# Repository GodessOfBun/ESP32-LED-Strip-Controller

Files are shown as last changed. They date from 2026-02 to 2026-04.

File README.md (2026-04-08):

## Introduction:front_3D

This ESP32-C2 Based board is designed to control up to 5 channels of an LED Strip. Each channel is in theory capable of 4A up to 24V with the total current drawn from the board not exceeding 5A. Although in theory there isn't much preventing it from reaching 8A current(eFuse max) other than trace width and the bulk capacitor and so on.
Mosfet remains below 50c with a 99% duty cycle at 2.4A/24v @ 25KHz in testing. In theory, according to my calculations, it can easily handle 4A or even 4.5A/5A. above 4A is not recommended. It is compatible with Matter (using the code I'm too eepy and busy to upload right now) and HA with ESPHome. If you use HA  you might as well save yourself the trouble and use ESPHome as Matter can have it's own shortcomings.

Measured Channel FET rise time: 12.5ns.

eFuse can be skipped by shorting the VIN to EFUSE to the output with a wire.

The board is designed for 25KHz in mind but can be used with a lower or higher frequency within reason.

You can leave unused channnels empty and not solder them to save on cost. 

The EFUSE is connfigured to be triggered at 5.51A. It features a 150ms-300ms~ soft-start to prevent sparks when connecting the power.

Note: It features a 0201 test LED originally used as a fun challenge for soldering. I suggest changing it to a 0602/0402 package if using it in practice or debugging with it as it can be very challenging to solder.

A IPEX connector is used to debug and monitor the 3.3v rail ripple and transient performance. Note however that the 50 ohm termination seems to not be working, I will confirm why when the project is finished as it's not essential and works perfectly fine with a probe tip to BNC adapter as the probe is designed to be purposely lossy and cancel ringing. A BNC to IPEX Cable is recommended. Note that IPEX connectors are not meant for frequent unplugging and replugging. The socket is rated for 30-50 mating cycles

### Notes:
Frequency of 2.2MHz was chosen for the 3.3v rail to improve transient response and performance/size of the buck converter. Efficiency is not a big concern for such an application.
An eFuse (Hot-swap controller) was chosen for this board to prevent sparking upon plugging in and to reduce the required footprint for an ressetable poly fuse that can withstand 40-30v at 5A.

## Potential  Improvemtns:
- [ ] Add a factory reset button seperate from BOOT
- [ ] External antenna instead of built-in PCB
- [ ] Switch from ESP32-C2 to C3 or similiar for better matter compatbility and performance.
- [ ] Use a dedicated ESP32 IC instead of a pre-made module as the PCB is already 4 layers hence the impedance matching is very easy and does not add additional cost.
- [ ] Add a polymer/tantalum bulk cap for esp32 to reduce wifi transmission transients. This will require some consideration to prevent ringing at the output.
- [ ] Calculate and confirm feed-forward capacitor for the 3.3v rail. (It is picked based on gut feeling)
- [ ] Improve hand-solderability, use bigger TVS diodes.
- [ ] Add jumper for 3.3v from programming header.
- [ ] (?) Debug LED for each channel
- [ ] (?) RGB Indicator LED for when WiFI is connected and device is commisioned.
- [ ] (?) Software based SSFM solution for each channel to reduce EMI emitted from the LED Strips as they are difficult to shield and user assembled. For a simpler but less effective solution, Each channel can operate at a slightly different ferquency.
- [ ] (?) eFuse skip jumper.

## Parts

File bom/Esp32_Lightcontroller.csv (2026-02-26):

Id | Designator | Footprint | Quantity | Designation | Supplier and ref
1 | C13,C20,C18 | C_0805_2012Metric | 3 | 1uF
2 | Q4,Q5,Q3,Q2,Q1 | SOT-23 | 5 | SI2318A
3 | L1 | L_Coilcraft_XAL6060-XXX | 1 | 8.2uH
4 | C14 | C_0402_1005Metric | 1 | 47pF
5 | R10 | R_0603_1608Metric | 1 | 22.1k 1%
6 | R4 | R_0603_1608Metric | 1 | 3kR 1%
7 | C21,C19,C5,C4 | C_1210_3225Metric | 4 | 10uF
8 | R3,R5,R7,R11,R9 | R_0603_1608Metric | 5 | 5
9 | C8,C10,C11,C9,C6,C27 | C_0402_1005Metric | 6 | 100nF
10 | C22 | C_0805_2012Metric | 1 | 4.7uF (X7R)
11 | U3,U4,U7,U5,U6 | SOT95P280X145-5N | 5 | UCC27517DBVR
12 | C2 | C_1206_3216Metric | 1 | 2.2uF
13 | D6 | LED_0603_1608Metric | 1 | LED_ON
14 | R13 | R_0603_1608Metric | 1 | 330R
15 | TP2 | TestPoint_Pad_D1.5mm | 1 | GPIO6
16 | U1 | ESP32-C2-C12 | 1 | ESP32-C2-C12
17 | R15 | R_0603_1608Metric | 1 | 50R Ter(opt)
18 | J3 | TerminalBlock_MaiXu_MX126-5.0-06P_1x06_P5.00mm | 1 | LED_Connector
19 | FB1 | Ferrite_0603_1608Metric | 1 | 600R 100mhz
20 | TP6 | U.FL_Molex_MCRF_73412-0110_Vertical | 1 | UMCC
21 | C16,C12,C3 | C_0603_1608Metric | 3 | 100nF
22 | SW1 | SW_Push_SPST_NO_Alps_SKRK | 1 | RST
23 | U8 | SOIC-8_3.9x4.9mm_P1.27mm | 1 | LM317L_SOT-89
24 | C7 | CP_Elec_6.3x7.7 | 1 | 100uF
25 | D13 | LED_0201_0603Metric | 1 | P18
26 | C15 | C_1206_3216Metric | 1 | 1uF
27 | U9 | TSOT-23-6 | 1 | AP64060WU-7
28 | C17 | CP_Radial_D10.0mm_P5.00mm | 1 | 470uF
29 | TP3 | TestPoint_Pad_D1.5mm | 1 | GPIO7
30 | R12 | R_0603_1608Metric | 1 | 69.8k 1%
31 | J1 | PinHeader_2x03_P1.27mm_Vertical | 1 | Conn_programmer
32 | C1 | C_1210_3225Metric | 1 | 10uF (50v)
33 | TP1 | TestPoint_Pad_D1.5mm | 1 | GPIO5
34 | R1,R2 | R_0603_1608Metric | 2 | 500
35 | 3.3v1 | Scope_probe_pad | 1 | Probe_3v3
36 | R6 | R_0603_1608Metric | 1 | 470R 1%
37 | J2 | TerminalBlock_CUI_TB007-508-02_1x02_P5.08mm_Horizontal | 1 | PWR
38 | SW2 | SW_Push_SPST_NO_Alps_SKRK | 1 | BOOT
39 | TP5 | TestPoint_Pad_D1.5mm | 1 | GPIO18
40 | TP4 | TestPoint_Pad_D1.5mm | 1 | GPIO10
41 | R14 | R_0201_0603Metric | 1 | 330R
42 | D2,D3,D4 | D_SOD-323 | 3 | 1N5819WS
43 | D11,D12,D8,D9,D10 | D_SOD-523 | 5 | 5v
44 | C24 | C_0402_1005Metric | 1 | 10nF
45 | C26 | C_0402_1005Metric | 1 | 8nF
46 | D5,D1 | D_SOD-323 | 2 | B5819WS
47 | D14 | D_SOD-123 | 1 | D_Schottky
48 | R18 | R_0603_1608Metric | 1 | 1M
49 | R17 | R_0603_1608Metric | 1 | 330k
50 | U2 | VQFN24_RGE_TEX | 1 | TPS259807ONRGER
51 | R8 | R_0603_1608Metric | 1 | 330
52 | C25 | C_0402_1005Metric | 1 | 68nF
53 | D7 | D_SOD-123F | 1 | TVS (26v)
54 | C23 | C_0402_1005Metric | 1 | 4.3nF
55 | R16 | R_0603_1608Metric | 1 | 2.21k

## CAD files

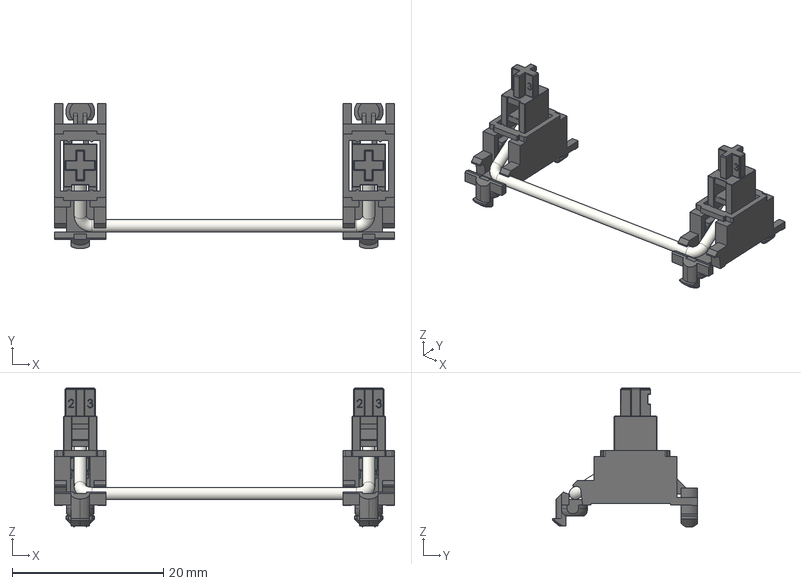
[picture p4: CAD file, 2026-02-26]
Footprints/kiswitch-main/source_3d/Mounting_Keyboard_Stabilizer/Stabilizer_Cherry_MX_3u.FCStd
44.9 x 19.2 x 18.3 mm
Bar
Stabilizer_Key_
Stabilizer_Base_
Stabilizer_Key
Stabilizer_Base

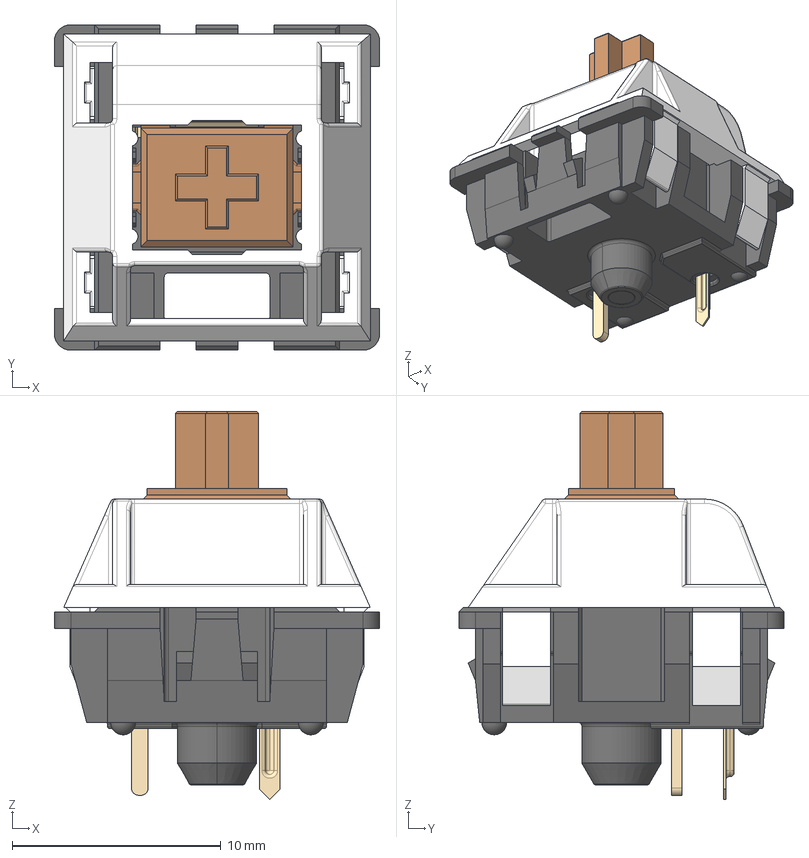
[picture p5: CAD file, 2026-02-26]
Footprints/kiswitch-main/source_3d/Switch_Keyboard_Cherry_MX/SW_Cherry_MX_Plate.FCStd
15.6 x 15.6 x 18.6 mm
Lower_Housing
Upper_Housing
Stem
Pin_1
Pin_2
Spring
Clicker

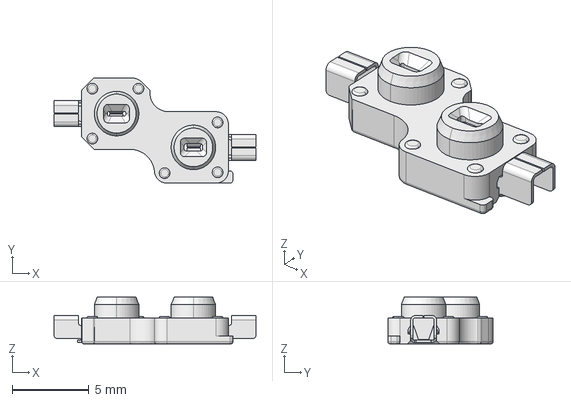
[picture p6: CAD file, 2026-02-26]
Footprints/kiswitch-main/source_3d/Switch_Keyboard_Kailh/SW_Hotswap_Kailh_Choc_v1.FCStd
13.2 x 6.85 x 3.05 mm

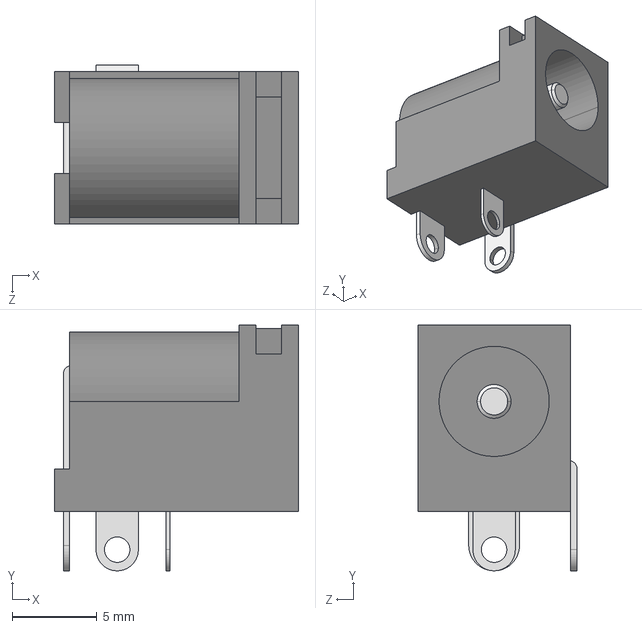
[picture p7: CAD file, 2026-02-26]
Footprints/PJ-002AH/PJ-002AH.step
14.4 x 14.5 x 9.40 mm

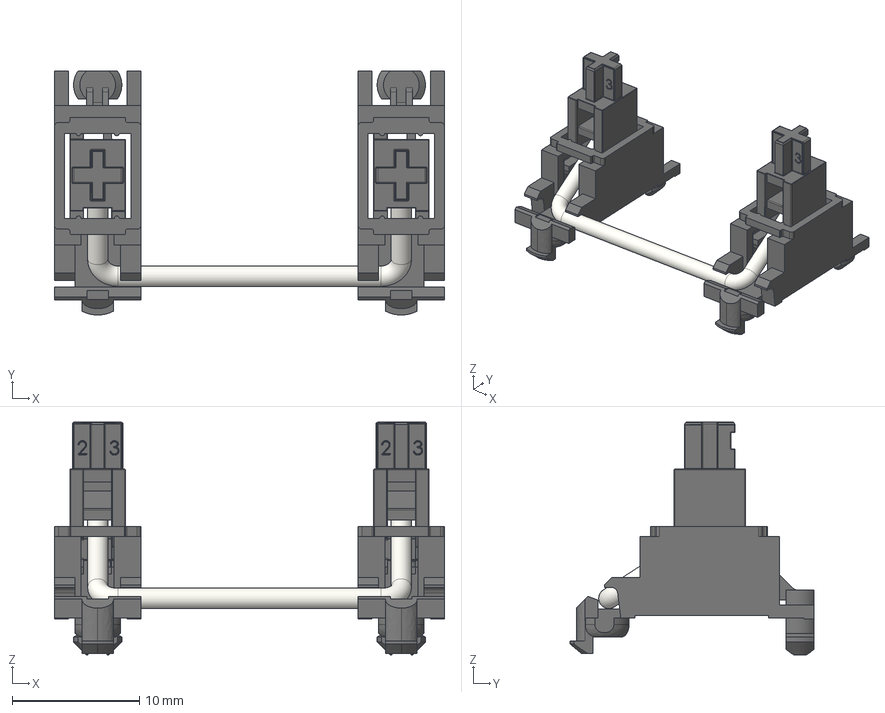
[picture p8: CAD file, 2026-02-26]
Footprints/kiswitch-main/source_3d/Mounting_Keyboard_Stabilizer/Stabilizer_Cherry_MX_2u.FCStd
30.7 x 19.2 x 18.3 mm
Bar
Stabilizer_Key_
Stabilizer_Base_
Stabilizer_Key
Stabilizer_Base

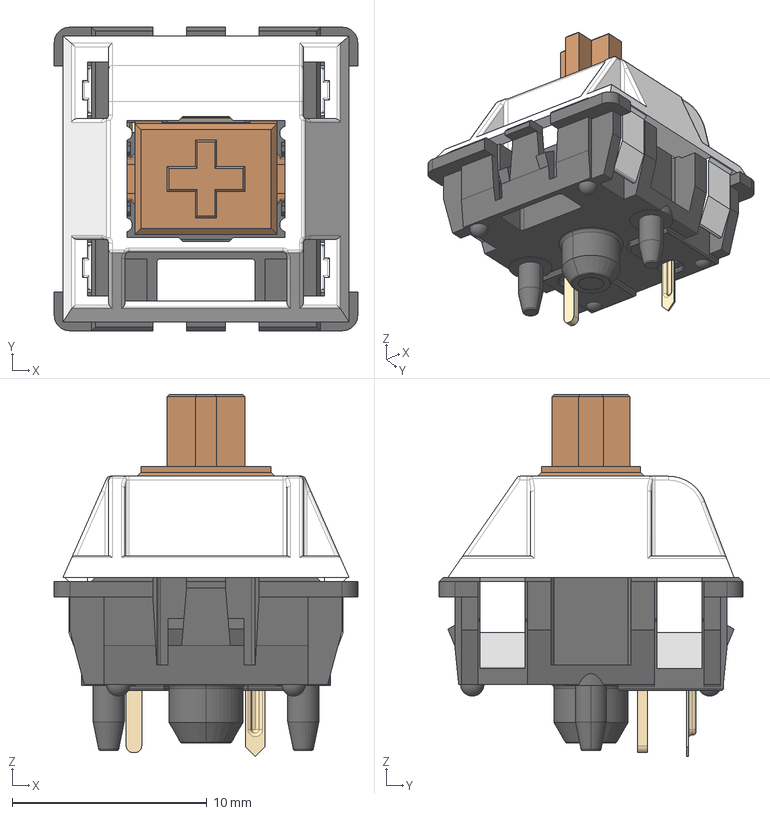
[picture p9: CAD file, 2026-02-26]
Footprints/kiswitch-main/source_3d/Switch_Keyboard_Cherry_MX/SW_Cherry_MX_PCB.FCStd
15.6 x 15.6 x 18.6 mm
Lower_Housing
Upper_Housing
Stem
Pin_1
Pin_2
Spring
Clicker

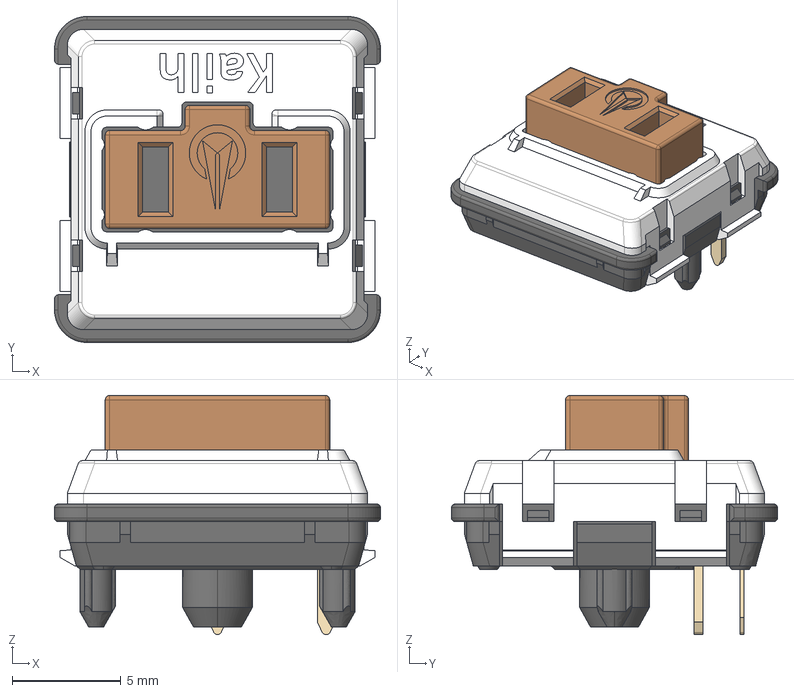
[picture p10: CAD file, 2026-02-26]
Footprints/kiswitch-main/source_3d/Switch_Keyboard_Kailh/SW_Kailh_Choc_V1.FCStd
15.0 x 15.0 x 11.0 mm
Upper_Housing
Lower_Housing
Stem
Pin_2
Pin_1

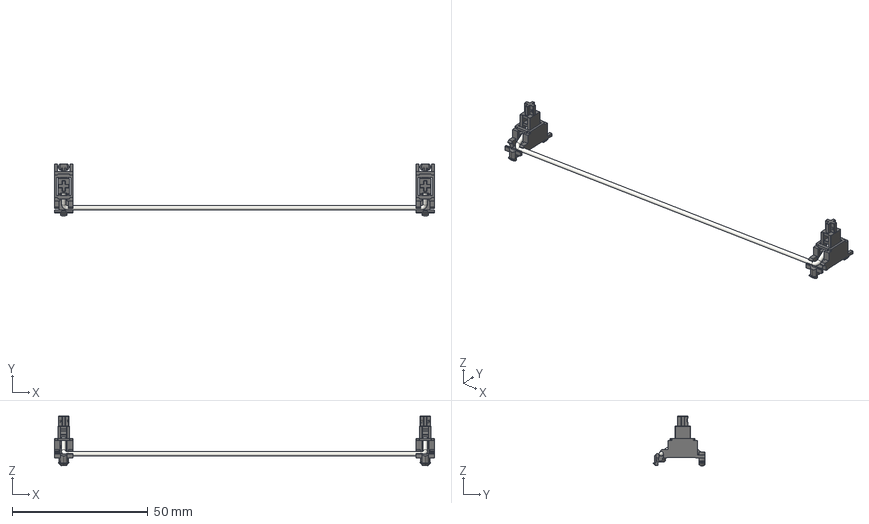
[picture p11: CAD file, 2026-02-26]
Footprints/kiswitch-main/source_3d/Mounting_Keyboard_Stabilizer/Stabilizer_Cherry_MX_8u.FCStd
140.1 x 19.2 x 18.3 mm
Bar
Stabilizer_Key_
Stabilizer_Base_
Stabilizer_Key
Stabilizer_Base

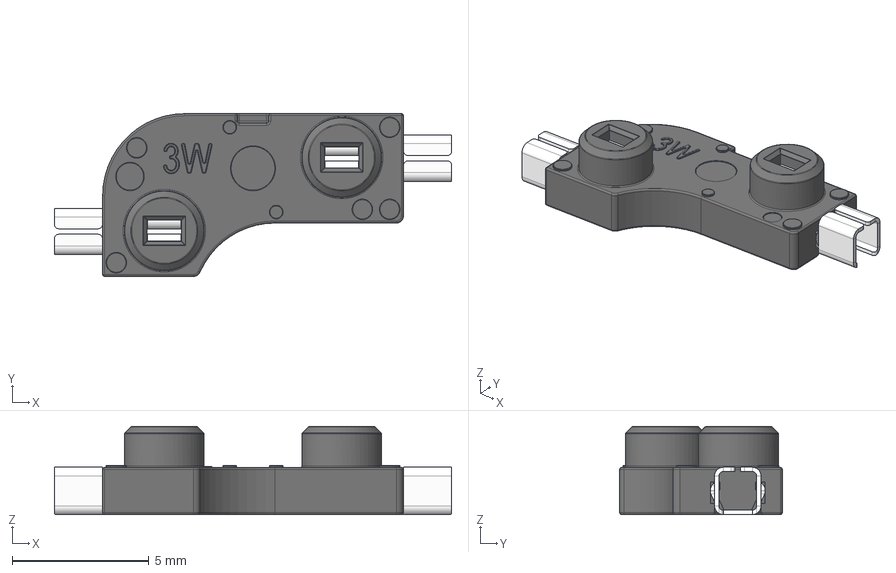
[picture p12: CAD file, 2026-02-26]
Footprints/kiswitch-main/source_3d/Switch_Keyboard_Kailh/SW_Hotswap_Kailh.FCStd
14.5 x 5.95 x 3.22 mm
Pin_1
Pin_2
Plastic

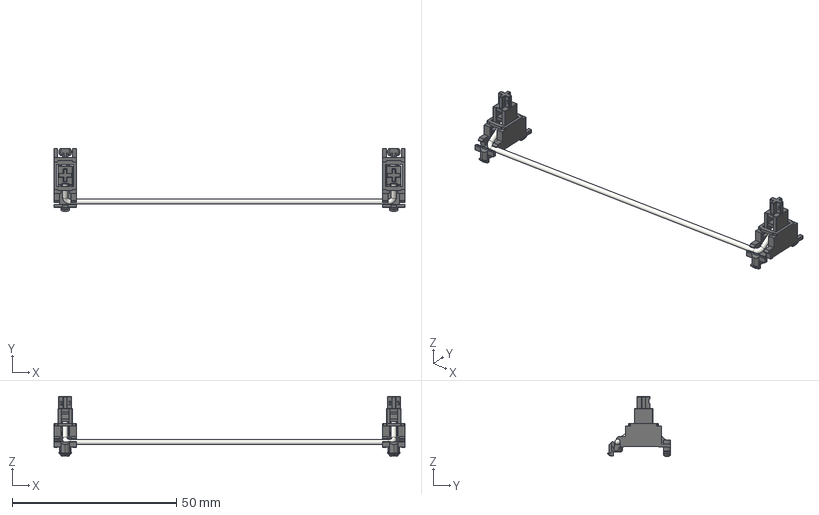
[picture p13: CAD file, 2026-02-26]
Footprints/kiswitch-main/source_3d/Mounting_Keyboard_Stabilizer/Stabilizer_Cherry_MX_6.25u.FCStd
106.8 x 19.2 x 18.3 mm
Bar
Stabilizer_Key_
Stabilizer_Base_
Stabilizer_Key
Stabilizer_Base

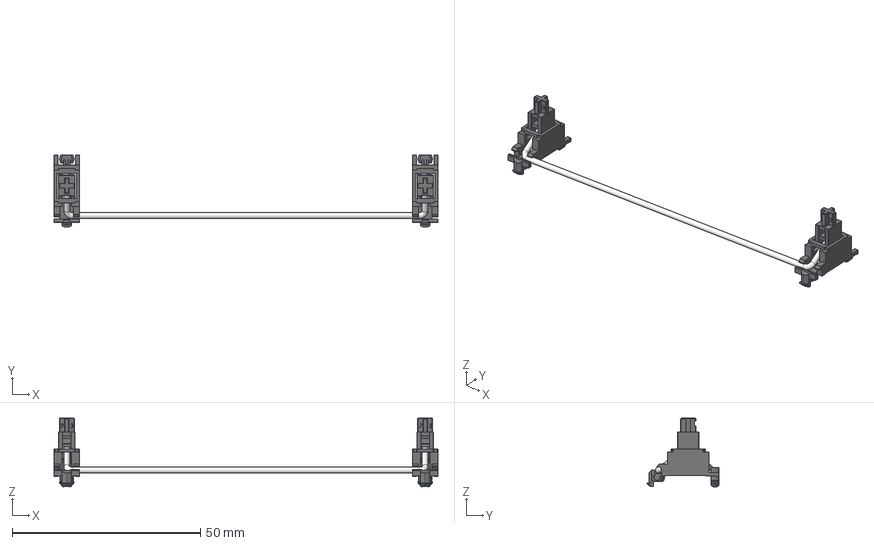
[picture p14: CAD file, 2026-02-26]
Footprints/kiswitch-main/source_3d/Mounting_Keyboard_Stabilizer/Stabilizer_Cherry_MX_6u.FCStd
102.1 x 19.2 x 18.3 mm
Bar
Stabilizer_Key_
Stabilizer_Base_
Stabilizer_Key
Stabilizer_Base

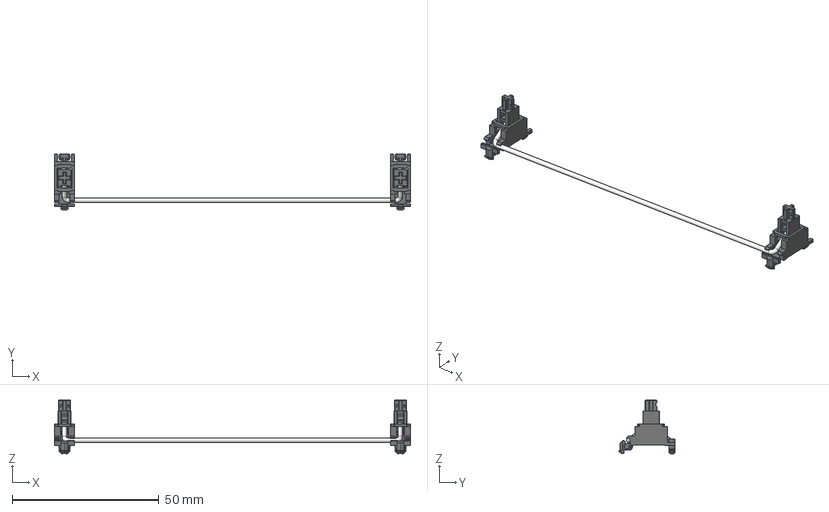
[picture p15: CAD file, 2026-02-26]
Footprints/kiswitch-main/source_3d/Mounting_Keyboard_Stabilizer/Stabilizer_Cherry_MX_7u.FCStd
121.1 x 19.2 x 18.3 mm
Bar
Stabilizer_Key_
Stabilizer_Base_
Stabilizer_Key
Stabilizer_Base

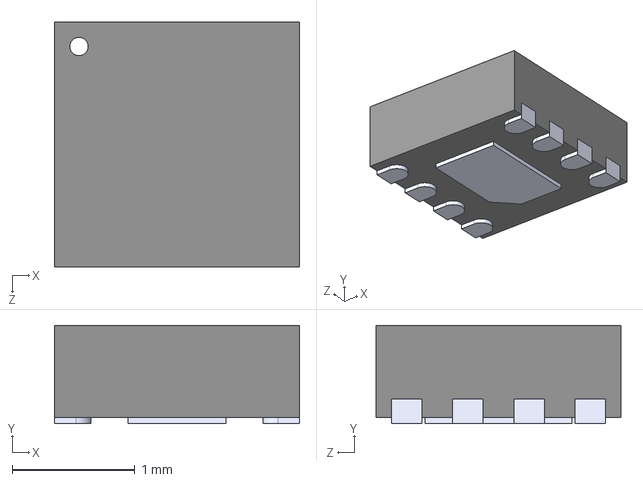
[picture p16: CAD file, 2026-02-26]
Footprints/MAX17048G+T10/MAX17048G_T10.step
2.00 x 0.8 x 2.00 mm

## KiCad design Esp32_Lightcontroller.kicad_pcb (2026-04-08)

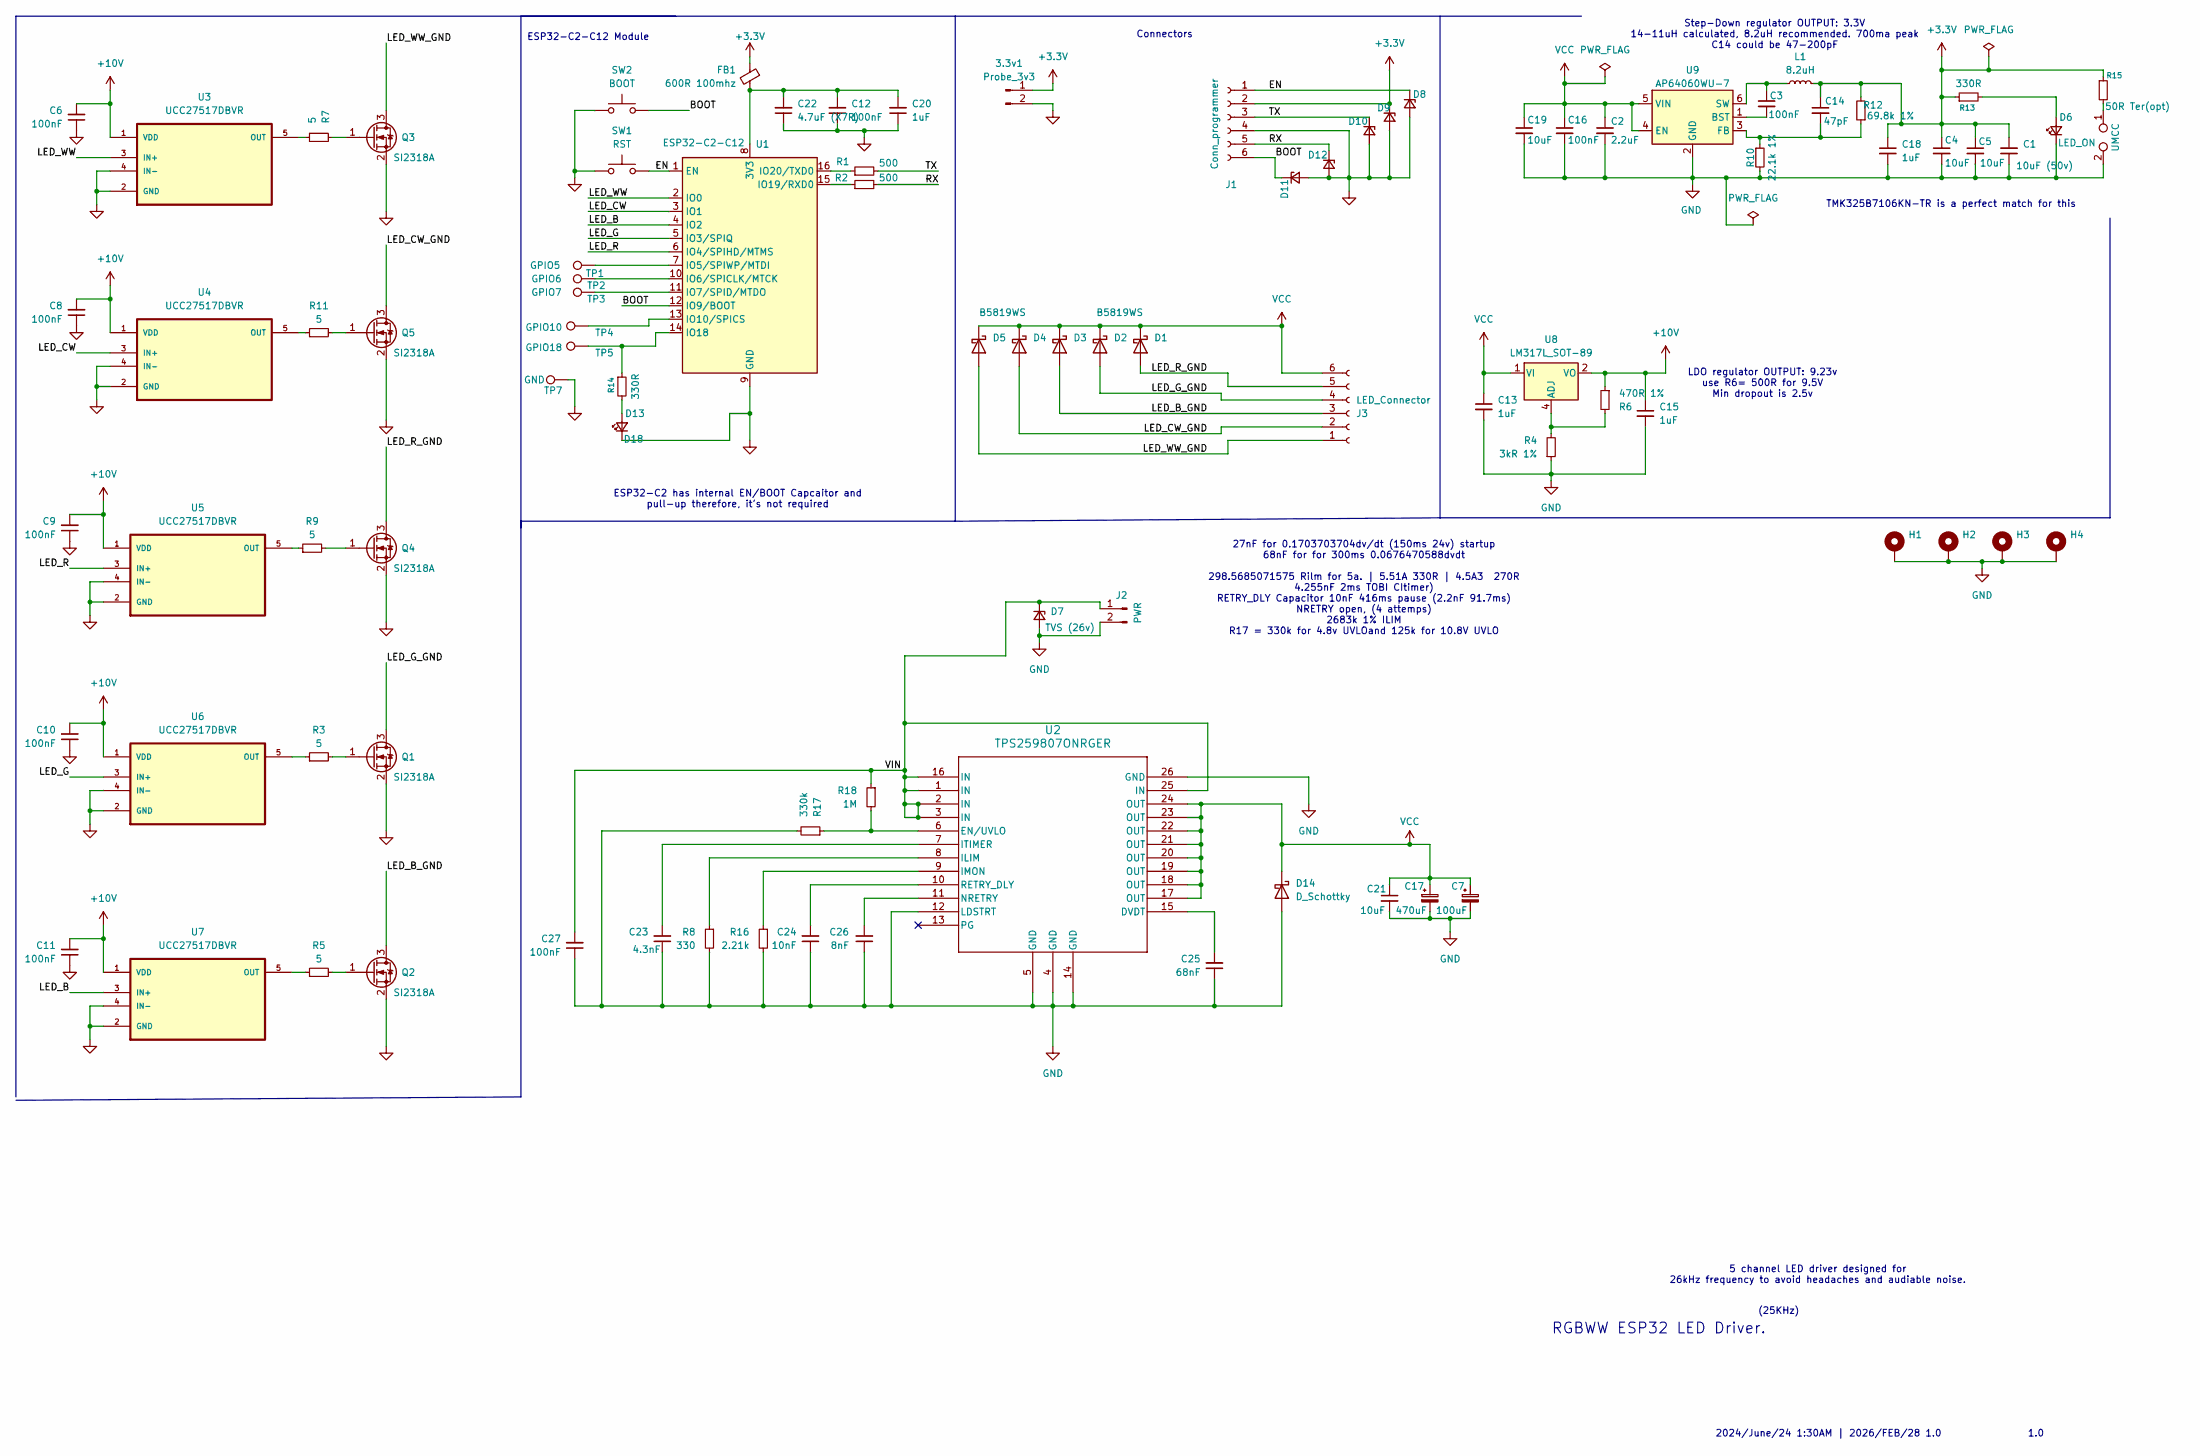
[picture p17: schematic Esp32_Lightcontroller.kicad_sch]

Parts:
3.3v1: Probe_3v3; Scope_probe_pad
C1: 10uF (50v); C_1210_3225Metric
C2: 2.2uF; C_1206_3216Metric
C3, C12, C16: 100nF; C_0603_1608Metric
C4, C5, C19, C21: 10uF; C_1210_3225Metric
C6, C8, C9, C10, C11, C27: 100nF; C_0402_1005Metric
C7: 100uF; CP_Elec_6.3x7.7
C13, C18, C20: 1uF; C_0805_2012Metric
C14: 47pF; C_0402_1005Metric
C15: 1uF; C_1206_3216Metric
C17: 470uF; CP_Radial_D10.0mm_P5.00mm
C22: 4.7uF (X7R); C_0805_2012Metric
C23: 4.3nF; C_0402_1005Metric
C24: 10nF; C_0402_1005Metric
C25: 68nF; C_0402_1005Metric
C26: 8nF; C_0402_1005Metric
D1, D5: B5819WS; D_SOD-323
D2, D3, D4: 1N5819WS; D_SOD-323
D6: LED_ON; LED_0603_1608Metric
D7: TVS (26v); D_SOD-123F
D8, D9, D10, D11, D12: 5v; D_SOD-523
D13: D18; LED_0201_0603Metric
D14: D_Schottky; D_SOD-123
FB1: 600R 100mhz; Ferrite_0603_1608Metric
H1, H2, H3, H4: MountingHole_Pad; MountingHole_3.2mm_M3_DIN965_Pad_TopBottom
J1: Conn_programmer; PinHeader_2x03_P1.27mm_Vertical
J2: PWR; TerminalBlock_CUI_TB007-508-02_1x02_P5.08mm_Horizontal
J3: LED_Connector; TerminalBlock_MaiXu_MX126-5.0-06P_1x06_P5.00mm
L1: 8.2uH; L_Coilcraft_XAL6060-XXX
Q1, Q2, Q3, Q4, Q5: SI2318A; SOT-23
R1, R2: 500; R_0603_1608Metric
R3, R5, R7, R9, R11: 5; R_0603_1608Metric
R4: 3kR 1%; R_0603_1608Metric
R6: 470R 1%; R_0603_1608Metric
R8: 330; R_0603_1608Metric
R10: 22.1k 1%; R_0603_1608Metric
R12: 69.8k 1%; R_0603_1608Metric
R13: 330R; R_0603_1608Metric
R14: 330R; R_0201_0603Metric
R15: 50R Ter(opt); R_0603_1608Metric
R16: 2.21k; R_0603_1608Metric
R17: 330k; R_0603_1608Metric
R18: 1M; R_0603_1608Metric
SW1: RST; SW_Push_SPST_NO_Alps_SKRK
SW2: BOOT; SW_Push_SPST_NO_Alps_SKRK
TP1: GPIO5; TestPoint_Pad_D1.5mm
TP2: GPIO6; TestPoint_Pad_D1.5mm
TP3: GPIO7; TestPoint_Pad_D1.5mm
TP4: GPIO10; TestPoint_Pad_D1.5mm
TP5: GPIO18; TestPoint_Pad_D1.5mm
TP6: UMCC; U.FL_Molex_MCRF_73412-0110_Vertical
TP7: GND; TestPoint_Pad_D1.5mm
U1: ESP32-C2-C12
U2: TPS259807ONRGER; VQFN24_RGE_TEX
U3, U4, U5, U6, U7: UCC27517DBVR; SOT95P280X145-5N; DigiKey_Part_Number 296-39527-1-ND
U8: LM317L_SOT-89; SOIC-8_3.9x4.9mm_P1.27mm
U9: AP64060WU-7; TSOT-23-6

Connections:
+3.3V: 3.3v1.1, C1.2, C4.1, C5.1, C14.1, C18.1, D9.1 (K), FB1.1, J1.2, L1.2, R12.2, R13.1, R15.1
+10V: C6.2, C8.2, C9.2, C10.2, C11.2, C15.1, R6.1, U3.1 (VDD), U4.1 (VDD), U5.1 (VDD), U6.1 (VDD), U7.1 (VDD), U8.2 (VO), U8.3 (VO), U8.6 (VO), U8.7 (VO)
/BOOT: D11.1 (K), J1.6, SW2.2, U1.12 (IO9/BOOT)
/EN: D8.1 (K), J1.1, SW1.2, U1.1 (EN)
/LED_B: U1.4 (IO2), U7.3 (IN+)
/LED_B_GND: D3.2 (A), J3.3, Q2.3 (D)
/LED_CW: U1.3 (IO1), U4.3 (IN+)
/LED_CW_GND: D4.2 (A), J3.2, Q5.3 (D)
/LED_G: U1.5 (IO3/SPIQ), U6.3 (IN+)
/LED_G_GND: D2.2 (A), J3.4, Q1.3 (D)
/LED_R: U1.6 (IO4/SPIHD/MTMS), U5.3 (IN+)
/LED_R_GND: D1.2 (A), J3.5, Q4.3 (D)
/LED_WW: U1.2 (IO0), U3.3 (IN+)
/LED_WW_GND: D5.2 (A), J3.1, Q3.3 (D)
/RX: D12.1 (K), J1.5, R2.2
/TX: D10.1 (K), J1.3, R1.2
/VIN: C27.2, D7.1 (K), J2.1, R18.1, U2.1 (IN), U2.2 (IN), U2.3 (IN), U2.16 (IN), U2.25 (IN)
GND: 3.3v1.2, C1.1, C2.2, C4.2, C5.2, C6.1, C7.2, C8.1, C9.1, C10.1, C11.1, C12.1, C13.2, C15.2, C16.2, C17.2, C18.2, C19.2, C20.1, C21.2, C22.1, C23.1, C24.1, C25.1, C26.1, C27.1, D6.1 (K), D7.2 (A), D8.2 (A), D9.2 (A), D10.2 (A), D11.2 (A), D12.2 (A), D13.1 (K), D14.2 (A), H1.1, H2.1, H3.1, H4.1, J1.4, J2.2, Q1.2 (S), Q2.2 (S), Q3.2 (S), Q4.2 (S), Q5.2 (S), R4.1, R8.2, R10.2, R16.2, R17.2, SW1.1, SW2.1, TP6.2, TP7.1, U1.9 (GND), U2.4 (GND), U2.5 (GND), U2.12 (LDSTRT), U2.14 (GND), U2.26 (GND), U3.2 (GND), U3.4 (IN-), U4.2 (GND), U4.4 (IN-), U5.2 (GND), U5.4 (IN-), U6.2 (GND), U6.4 (IN-), U7.2 (GND), U7.4 (IN-), U9.2 (GND)
unnamed: D6.2 (A), R13.2
unnamed: D13.2 (A), R14.2
unnamed: Q1.1 (G), R3.2
unnamed: Q2.1 (G), R5.2
unnamed: Q3.1 (G), R7.2
unnamed: Q4.1 (G), R9.2
unnamed: Q5.1 (G), R11.2
unnamed: R15.2, TP6.1
unnamed: C12.2, C20.2, C22.2, FB1.2, U1.8 (3V3)
unnamed: TP1.1, U1.7 (IO5/SPIWP/MTDI)
unnamed: TP2.1, U1.10 (IO6/SPICLK/MTCK)
unnamed: TP3.1, U1.11 (IO7/SPID/MTDO)
unnamed: TP4.1, U1.13 (IO10/SPICS)
unnamed: R14.1, TP5.1, U1.14 (IO18)
unnamed: R2.1, U1.15 (IO19/RXD0)
unnamed: R1.1, U1.16 (IO20/TXD0)
unnamed: C25.2, U2.15 (DVDT)
unnamed: R17.1, R18.2, U2.6 (EN/UVLO)
unnamed: R8.1, U2.8 (ILIM)
unnamed: R16.1, U2.9 (IMON)
unnamed: C23.2, U2.7 (ITIMER)
unnamed: C26.2, U2.11 (NRETRY)
unnamed: C24.2, U2.10 (RETRY_DLY)
unnamed: R7.1, U3.5 (OUT)
unnamed: R11.1, U4.5 (OUT)
unnamed: R9.1, U5.5 (OUT)
unnamed: R3.1, U6.5 (OUT)
unnamed: R5.1, U7.5 (OUT)
unnamed: R4.2, R6.2, U8.4 (ADJ)
unnamed: C3.2, U9.1 (BST)
unnamed: C14.2, R10.1, R12.1, U9.3 (FB)
unnamed: C3.1, L1.1, U9.6 (SW)
VCC: C2.1, C7.1, C13.1, C16.1, C17.1, C19.1, C21.1, D1.1 (K), D2.1 (K), D3.1 (K), D4.1 (K), D5.1 (K), D14.1 (K), J3.6, U2.17 (OUT), U2.18 (OUT), U2.19 (OUT), U2.20 (OUT), U2.21 (OUT), U2.22 (OUT), U2.23 (OUT), U2.24 (OUT), U8.1 (VI), U9.4 (EN), U9.5 (VIN)

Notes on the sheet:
LDO regulator OUTPUT: 9.23v use R6= 500R for 9.5V Min dropout is 2.5v
5 channel LED driver designed for 26kHz frequency to avoid headaches and audiable noise.
ESP32-C2 has internal EN/BOOT Capcaitor and pull-up therefore, it's not required
Step-Down regulator OUTPUT: 3.3V 14-11uH calculated, 8.2uH recommended. 700ma peak C14 could be 47-200pF
ESP32-C2-C12 Module
(25KHz)
TMK325B7106KN-TR is a perfect match for this
2024/June/24 1:30AM | 2026/FEB/28 1.0
RGBWW ESP32 LED Driver.
27nF for 0.1703703704dv/dt (150ms 24v) startup 68nF for for 300ms 0.0676470588dvdt 298.5685071575 Rilm for 5a. | 5.51A 330R | 4.5A3 270R 4.255nF 2ms TOBI CItimer) RETRY_DLY Capacitor 10nF 416ms pause (2.2nF 91.7ms) NRETRY open, (4 attemps) 2683k 1% ILIM R17 = 330k for 4.8v UVLOand 125k for 10.8V UV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
1.0
Connectors

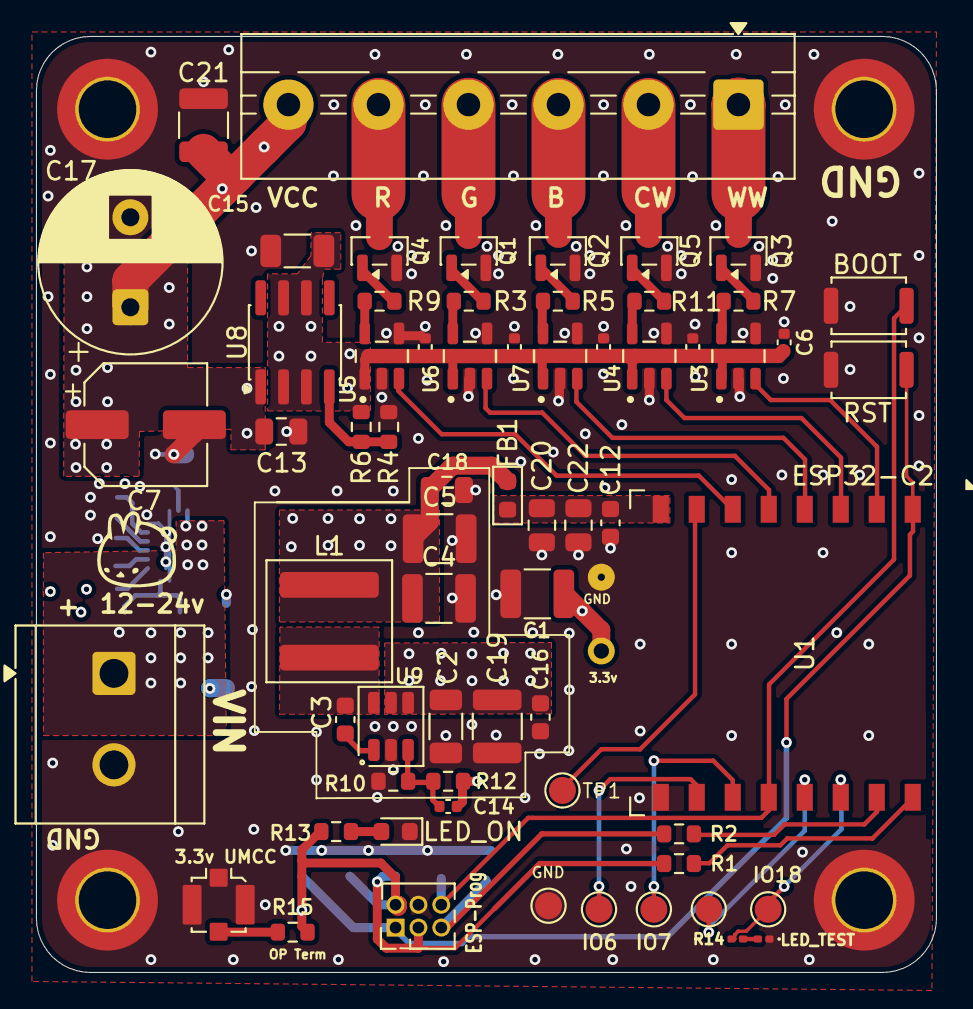
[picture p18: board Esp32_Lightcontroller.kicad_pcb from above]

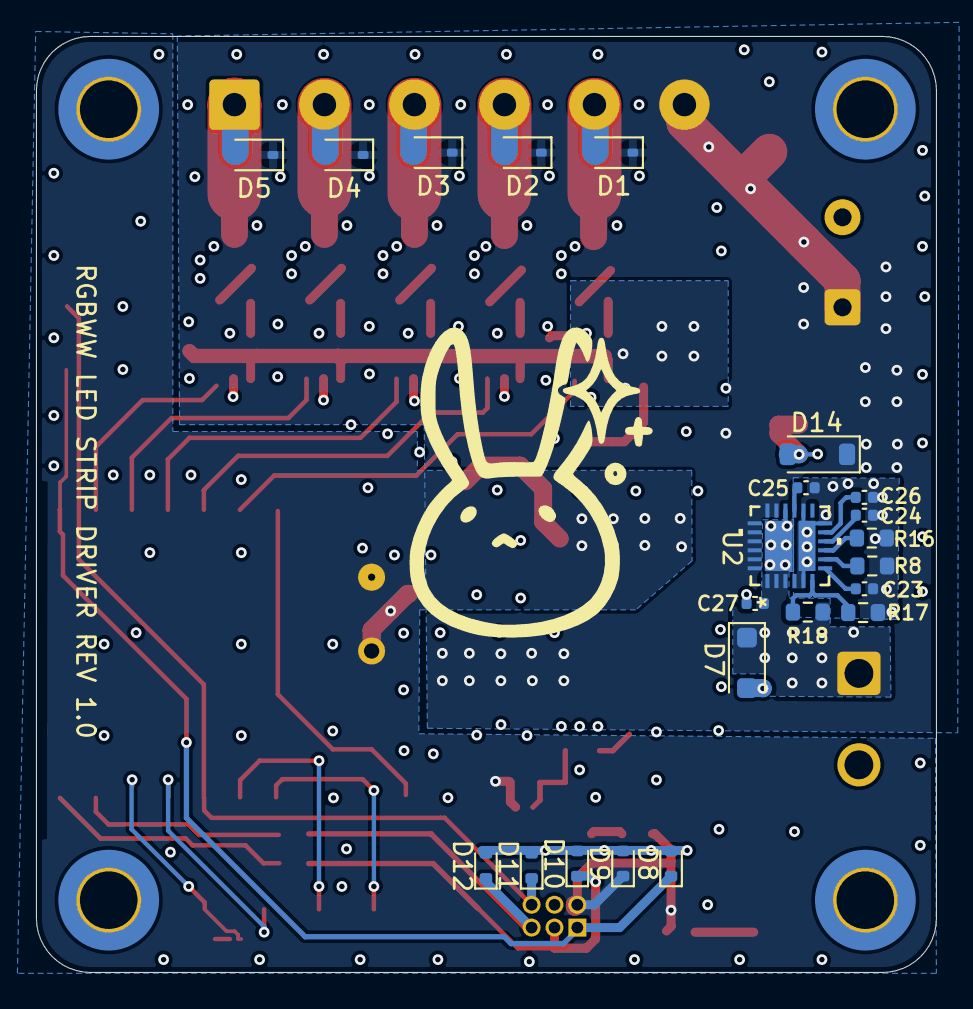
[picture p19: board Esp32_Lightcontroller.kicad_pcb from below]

Board: 4 copper layers, 50.0 x 52.0 mm, 92 parts (22 on the bottom side), 51 nets.

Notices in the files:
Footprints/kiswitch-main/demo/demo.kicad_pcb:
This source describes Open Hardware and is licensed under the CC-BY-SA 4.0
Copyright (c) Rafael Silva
